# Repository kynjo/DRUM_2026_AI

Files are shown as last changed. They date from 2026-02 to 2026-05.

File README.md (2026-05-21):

# DRUM_2024_AI

All the changes were added using AI

ESP32 DRUM SYNTH MACHINE

DRUM SYNTH LOFI MACHINE.



# Synth engine:

- Wavetable synthesizer based on DZL Arduino library ["The Synth"](https://github.com/dzlonline/the_synth)
- 16 sound polyphony
- MIDI support
- Sound parameters: Table, Length, Envelope, Pitch, Modulation, + Volume, Pan and Filter.
- Filter (LowPassFilter) comes from [Mozzi Library](https://github.com/sensorium/Mozzi)
- Master delay (on 14 button).
- Wavetable's name on screen.
- BPM on main screen.

SEQUENCER:

- 16 step/pattern editor and random generators (pattern, sound parameters and notes)

# Hardware:

- Lolin S2 Mini (ESP32 S2)
- PCM5102A I2s dac
- 24 push buttons (8x3)
- Rotary encoder
- OLED display I2c
- 32 LED WS2812B

# Software:

IDE:
Arduino `1.8.19` 
Arduino `2.3.8`

Boards:
Expressif Systems `2.0.17`

Adafruit TinyUSB `2.4.0`

Board: Lolin S2 Mini

Necessary Libraries:

- Sequencer Timer - [uClock](https://github.com/midilab/uClock)
- RGB Leds - [Adafruit Neopixel](https://github.com/adafruit/Adafruit_NeoPixel)
- OLED - [u8g2](https://github.com/olikraus/u8g2)
- Button input - [Keypad](https://github.com/Chris--A/Keypad)

# Notes:

STL 3D model uploaded.

Cheat sheet style PDF uploaded.

Join solder pads near SCK pin on PCM5102A module.

**Update**: 

- Solder pads on the back of PCM5102A module ([more info](https://github.com/pschatzmann/ESP32-A2DP/wiki/External-DAC#pcm5102-dac))
  
  - H1L: FLT - Low
  
  - H2L: DEMP - Low
  
  - H3L: XSMT - High
  
  - H4L: FMT - Low

Video demo of the prototype:

(https://www.youtube.com/watch?v=rXl1gpWJp-g)

# PCB, PROJECT & FINAL LOOK:

https://oshwlab.com/zircothc/esp32-drum-synth-lofi-machine

https://easyeda.com/editor#project_id=08f629c08b18444ca16accbb2242c0fb





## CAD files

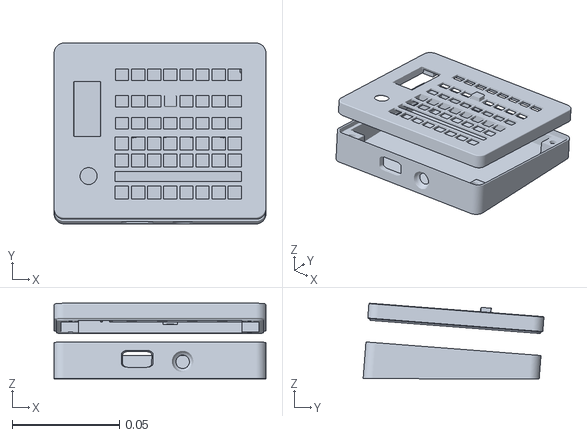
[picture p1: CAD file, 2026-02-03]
STL/all.stl
0.0988 x 0.0843 x 0.0352

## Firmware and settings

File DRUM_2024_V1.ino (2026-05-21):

////////////////////////////
// DRUM 2024              //
////////////////////////////
// ZCARLOS 2024
// Based on DZL's library "the_synth"
// Ported to ESP32 internal DACs but...
// DAC outs sounds very noisy
// Instead of modify the library I cut it into functions to try to port to pcm5102a i2s DAC out, DONE :)
// Extended tables up to 14 and voices up to 16
// Mixer section (L&R) per voice
// Filter per voice and master filter (from Mozzi library)


// includes
#include <Arduino.h>
////////////////////////////// SPIFFS
#include <FS.h>
#include <SPIFFS.h>

////////////////////////////// OLED
#include <U8g2lib.h>
#include <Wire.h>
////////////////////////////// SYNTH
#define SAMPLE_RATE 44100
#include "driver/i2s.h"
#include "synthESP32LowPassFilter_E.h" // filter
#include "tablesESP32_E.h"
//////////////////////////////DELAY
#include "reverbESP32.h"
//////////////////////////////RETRIGGER
#include "retriggerESP32.h"

////////////////////////////// LEDS
#include <Adafruit_NeoPixel.h>
////////////////////////////// TIMER SEQ 
#include <uClock.h>
////////////////////////////// KEYPAD
#include <Keypad.h>
////////////////////////////// MIDI USB
//#include <Adafruit_TinyUSB.h>
//#include <MIDI.h>
//MIDI_CREATE_INSTANCE(HardwareSerial, Serial2, MIDI);
#include <Adafruit_TinyUSB.h>
#include <MIDI.h>

Adafruit_USBD_MIDI usb_midi;
MIDI_CREATE_INSTANCE(Adafruit_USBD_MIDI, usb_midi, MIDI);

////////////////////////////////////////////////////////////////////////////////////////////
////////////////////////////////////////////////////////////////////////////////////////////

////////////////////////////// OLED
U8G2_SSD1306_128X32_UNIVISION_F_HW_I2C u8g2(U8G2_R3, /* reset=*/ U8X8_PIN_NONE, /* clock=*/ 5, /* data=*/ 3);   // pin remapping with ESP8266 HW I2C

const String trot[17] = { "WAV", "ENV", "LEN", "PIT", "MOD", "VOL", "PAN", "FIL", "BPM","MVO","TRP","MFI","OCT","PSN","DLY","RTG"};
const String waveNames[16] = {
  "SIN",  // 0 - Sine
  "TRI",  // 1 - Triangle  
  "SQR",  // 2 - Square
  "SAW",  // 3 - Saw
  "RMP",  // 4 - Ramp
  "NS",   // 5 - Noise
  "PHS",  // 6 - Phasor
  "ADD",   // 14 - Additive (если добавили)
  "SUB",  // 15 - Wave 7
  "WN1",  // 7 - Wave 1
  "WN2",  // 8 - Wave 2
  "WN3",  // 9 - Wave 3
  "WN4",  // 10 - Wave 4
  "WN5",  // 11 - Wave 5
  "WN6",  // 12 - Wave 6
  "WN7"  // 13 - Wave 7  
};
const String tmodeZ[20] = { "Pad", "Sel", "Write", "Mute", "Solo", "Clear","LoadP","LoadS","LoaPS","SaveP","SaveS","SavPS","RndS","RndP","First","Last","Melod","RndNo","Piano","Song"};

// modeZ types

//  0 - play pad sound
//  1 - select sound
//  2 - edit track, write
//  3 - mute
//  4 - solo
//  5 - clear

//  6 - load pattern
//  7 - load pattern
//  8 - load pattern and sound

//  9 - save pattern
// 10 - save sound
// 11 - save sound and pattern
 
// 12 - random sound
// 13 - random pattern
// 14 - first step
// 15 - last step
// 16 - set melodic (read pitch from pattern melodic instead of rotary value)
// 17 - random note
// 18 - piano
// 10 - song (edit song)

#define tPad    0
#define tSel    1
#define tWrite  2
#define tMute   3
#define tSolo   4
#define tClear  5
#define tLoadP  6
#define tLoadS  7
#define tLoaPS  8
#define tSaveP  9
#define tSaveS 10
#define tSavPS 11
#define tRndS  12
#define tRndP  13
#define tFirst 14
#define tLast  15
#define tMelod 16
#define tRndNo 17
#define tPiano 18
#define tSong  19

////////////////////////////// SYNTH
// i2s

#define I2S_BCK_PIN 33
#define I2S_WS_PIN 37
#define I2S_DATA_OUT_PIN 35

#define DMA_BUF_LEN     32          
#define DMA_NUM_BUF     2

static uint16_t out_buf[DMA_BUF_LEN * 2];



// Filters master (L&R) and 16 sounds
LowPassFilter lpfR;
LowPassFilter lpfL;

SimpleReverb masterReverb;
//SimpleRetrigger masterRetrigger; //retrigger

// Массив фильтров для 16 голосов — вместо lpf0..lpf15
LowPassFilter lpf[16];



const int revlevel=200;
const int cutoff=255;
const int reso=511;

int vmeter=0;

static unsigned int PCW[16] = {0, 0, 0, 0,0 ,0 ,0 ,0,0, 0, 0, 0,0 ,0 ,0 ,0};      //-Wave phase accumolators
static unsigned int FTW[16] = {1000, 200, 300, 400, 1000, 200, 300, 400, 1000, 200, 300, 400, 1000, 200, 300, 400};           //-Wave frequency tuning words
static unsigned char AMP[16] = {255, 255, 255, 255, 255, 255, 255, 255, 255, 255, 255, 255, 255, 255, 255, 255};           //-Wave amplitudes [0-255]
static unsigned int PITCH[16] = {500, 500, 500, 500, 500, 500, 500, 500, 500, 500, 500, 500, 500, 500, 500, 500};          //-Voice pitch
static int MOD[16] = {64, 64, 64, 64, 64, 64, 64, 64, 64, 64, 64, 64, 64, 64, 64, 64};                      //-Voice envelope modulation [0-1023 512=no mod. <64 pitch down >64 pitch up]

static int VOL_R[16] = {10, 10, 10, 10, 10, 10, 10, 10, 10, 10, 10, 10, 10, 10, 10, 10}; 
static int VOL_L[16] = {10, 10, 10, 10, 10, 10, 10, 10, 10, 10, 10, 10, 10, 10, 10, 10};   
static int PAN[16] = {10, 10, 10, 10, 10, 10, 10, 10, 10, 10, 10, 10, 10, 10, 10, 10}; 
static int FILTER[16]= {127, 127, 127, 127, 127, 127, 127, 127, 127, 127, 127, 127, 127, 127, 127, 127};                  //-mozzi FILTERS  0-255

static unsigned int wavs[16];                                  //-Wave table selector [address of wave in memory]
static unsigned int envs[16];                                  //-Envelope selector [address of envelope in memory]
static unsigned int EPCW[16] = {0x8000, 0x8000, 0x8000, 0x8000, 0x8000, 0x8000, 0x8000, 0x8000, 0x8000, 0x8000, 0x8000, 0x8000, 0x8000, 0x8000, 0x8000, 0x8000}; //-Envelope phase accumulator
static unsigned int EFTW[16] = {10, 10, 10, 10, 10, 10, 10, 10, 10, 10, 10, 10, 10, 10, 10, 10};               //-Envelope speed tuning word
static unsigned int divider = 16;                             //-Sample rate decimator for envelope

static int mvol=10;
int master_vol=17;
int master_filter=0;
int master_reverb=0;
//int master_retrigger = 0;  //retrigger
int octave=5;



////////////////////////////// LEDS
#define LED_PIN    39
#define LED_COUNT 32
Adafruit_NeoPixel strip(LED_COUNT, LED_PIN, NEO_GRB + NEO_KHZ800);
// Set more friendly led numbers
// 0 to 15 as 16 step, 16 sounds,... and 16 to 23 as selected modes
const byte real_led[32]={ 8, 9,10,11,24,25,26,27,15,14,13,12,31,30,29,28,
                          0, 1, 2, 3,16,17,18,19, 7, 6, 5, 4,23,22,21,20};
int counter_refresh=0;
const byte limit_counter_refresh=7;
boolean start_counter_refresh=false;

////////////////////////////// TIMER SEQ 
int bpm=120;
int stepInterval;
int microStep=0;
byte selected_pattern=0;
byte sstep=0;
byte selected_len=16;
boolean updateBPM=false;
uint16_t mutes=0;
uint16_t solos=0;
uint16_t pattern[16];
byte song[255];
int pattern_song_counter=-1;
byte last_pattern_song=255;
uint8_t  melodic[16][16];
//uint16_t isMelodic=B11111111<<8 | B00000000; // last 8 sounds are set to melodic
uint16_t isMelodic=B00000000<<8 | B00000000; // none set to melodic
byte firstStep=0;
byte lastStep=15;
byte newLastStep=15; 
byte selected_sound=0;
byte oldselected_sound=0;
byte selected_sndSet=0;
int transpose=0;
boolean load_flag=false;

////////////////////////////// ROTARY
void IRAM_ATTR i_ENCODERS();
const byte pinBR1=9;
const byte pinR1A=11;
const byte pinR1B=12;
byte ENC_PORT1=0;
int counter1=0;
int old_counter1=0;
boolean readencoders=false;
byte shiftR1=false;
byte RV;

// 8 sound parameters + bpm + master vol + transpose + master filter + octave + Pattern song selector +  4 Audino parameters
const int max_values[17]={15,4,127,127,127,31, 99,127,400,31, 1,127,10,255,255.255}; 
const int min_values[17]={ 0,0,  0,  0,  0, 0,-99,  0,  0, 0,-1,  0, 0,  0,  1, 0};

int ROTvalue[16][8]={ // init sound values
  { 0,2, 32, 35,29,7,-31,0}, // THIS IS VOICE #0
  { 5,1, 50,127,31,7,-31,0}, // THIS IS VOICE #1
  { 9,2, 25, 41,95,7,  0,0}, // ...
  { 0,0, 60, 64,30,7,  0,0},
  {13,2, 47, 44,82,7,  0,0},
  { 8,2, 42, 29,31,7,  0,0},
  { 0,0, 30, 54,64,7,  0,0},
  { 3,0, 25, 44,64,7,  0,0},
  
  { 0,2, 32, 25,29,7, 66,0},
  { 5,2, 50,107,31,7, 66,0},
  { 9,2, 25, 31,95,7,  0,0},
  { 0,0, 60, 54,30,7,  0,0},
  {13,2, 47, 54,82,7,  0,0},
  { 8,2, 42, 19,31,7,  0,0},
  { 0,0, 40, 44,64,7, 30,0},
  { 3,0, 80, 34,64,7,-30,0}
};

byte selected_rot=0;

////////////////////////////// KEYPAD

const byte ROWS = 8; //four rows
const byte COLS = 3; //three columns
char keys[ROWS][COLS] = {
  {'1','2','3'},
  {'4','5','6'},
  {'7','8','9'},
  {'*','0','#'},
  {'a','s','d'},
  {'z','x','c'},
  {'f','g','h'},
  {'v','b','n'}  
};
// need to confirm if this is the right order in the PCB version
byte rowPins[ROWS] = {14, 13, 10, 8,6,4,2,7}; //connect to the row pinouts of the keypad
byte colPins[COLS] = {40,38,36}; //connect to the column pinouts of the keypad
Keypad kpd = Keypad( makeKeymap(keys), rowPins, colPins, ROWS, COLS );
byte trigger_on[24];
byte nkey;

// Set more friendly key numbers
// 0 to 15 as 16 step, 16 sounds,... and 16 to 23 as selected modes
const byte real_key[24]={ 
 0, 8,16,
 1, 9,17,
 2,10,18,
 3,11,19,
 4,12,20,
 5,13,21,
 6,14,22,
 7,15,23
};

byte pad_touched=0;

////////////////////////////// MISC
byte modeZ=0;
byte last_modeZ=0;
byte last_sound=0;

volatile boolean playing = false;
boolean songing   = false; // switch to make load auto patterns++
boolean recording = false;
//boolean shifting  = false;

boolean clearPATTERN=false;
boolean clearSTEP=false;
boolean refreshPATTERN=true;
boolean refreshSTEP=false;
boolean refreshSTATUS=false;
boolean refreshMODES=true;
boolean refreshOLED=true;
boolean refreshPADTOUCHED=false;
boolean stepzero = false;

// Rate-limit для OLED и LED — не чаще чем раз в N мс
// Это освобождает loop() для обработки MIDI в остальное время
static uint32_t lastOLEDms = 0;
static uint32_t lastLEDms  = 0;
#define OLED_INTERVAL_MS  40   // ~25 fps достаточно для UI
#define LED_INTERVAL_MS   20   // ~50 fps для LED
#define MIDI_CLOCK 0xF8
#define MIDI_START 0xFA
#define MIDI_STOP  0xFC


////////////////////////////////////////////////////////////////////////////////////////////
////////////////////////////////////////////////////////////////////////////////////////////

void setSound(byte f){
  synthESP32_setWave(f,ROTvalue[f][0]);  
  synthESP32_setEnvelope(f,ROTvalue[f][1]);
  synthESP32_setLength(f,ROTvalue[f][2]);
  synthESP32_setPitch(f,ROTvalue[f][3]);
  synthESP32_setMod(f,ROTvalue[f][4]); 
  synthESP32_setVol(f,ROTvalue[f][5]);  
  synthESP32_setPan(f,ROTvalue[f][6]);  
  synthESP32_setFilter(f,ROTvalue[f][7]); 

  //////
}

/*
void handleNoteOn(uint8_t channel, uint8_t pitch, uint8_t velocity) {
  if (velocity == 0) {
    // Velocity 0 также иногда означает Note Off
    return handleNoteOff(channel, pitch, velocity);
  }
  // Воспроизводим ноту на соответствующем канале
  if (pitch < 16) { // Проверяем диапазон (0-15 каналов)
    byte soundChannel = pitch % 16;
    synthESP32_mTrigger(soundChannel, pitch);
  }
}

void handleNoteOff(uint8_t channel, uint8_t pitch, uint8_t velocity) {
  // Тут можно обнулять сэмплы/доп логика
  Serial.println("Note Off");
  // По вашему желанию. Например, отключить звук
}
*/



void setRandomVoice(byte f){
  ROTvalue[f][0]=random(0, 16);
  ROTvalue[f][1]=random(0, 5);
  ROTvalue[f][2]=random(1, 60);
  ROTvalue[f][3]=random(0, 127);
  ROTvalue[f][4]=random(10,100);
  ROTvalue[f][5]=random(10,15);
  ROTvalue[f][6]=random(-99,99);
  ROTvalue[f][7]=random(0,60);
}
void setRandomPattern(byte f){
  byte veces=random(0,2);
  for (byte b = 0; b < 16; b++) {
    byte mybit=random(0,2);
    if (veces) {
      if (mybit) mybit=random(0,2); // Si es 1 hago otro random para que haya menos unos
    }
    bitWrite(pattern[f],b,mybit);
  } 
  setRandomPitch(f);
}

void setRandomPitch(byte f){
  // Tomo como referencia para el rango el valor del pot pitch actual
  uint8_t actual=ROTvalue[selected_sound][3];
  uint8_t limite;
  uint8_t prelimite=24;
  if (shiftR1) prelimite = 24;
  for (byte b = 0; b < 16; b++) {
     limite=actual+random(0,prelimite);
     melodic[f][b]=random(actual-(prelimite>>1),limite);
  }  
}

void setRandomNotes(byte f){
  setRandomPitch(f);
}
////////////////////////////////////////////////////////////////////////////////////////////
////////////////////////////////////////////////////////////////////////////////////////////
void onSync24Callback(uint32_t tick){
  if (!playing) return;  // ISR не должен продолжать после Stop
  if (!(tick % (6))) tic(tick);
  if ((tick % (6))==4) clearPATTERN=true;
}

void tic(uint32_t tick){
  
//  if (playing){
    //if (microStep==0){
      clearSTEP=true;
      for (int f = 0; f < 16; f++) { 
        if (!bitRead(mutes, f)) {
          if (solos == 0 || (solos > 0 && bitRead(solos, f))) {
            if (bitRead(pattern[f], sstep)) { // note on
              if (bitRead(isMelodic,f)){
                //synthESP32_setPitch(f,melodic[f][sstep]);

                  synthESP32_mTrigger(f,melodic[f][sstep]);                  

              } else {
                // reestablecer el pitch
                synthESP32_setPitch(f,ROTvalue[f][3]);                
                synthESP32_trigger(f);
              }
            } 
          }
        }
      }
  
      sstep++;
      // Comprobar step final
      if (sstep==(lastStep+1) || sstep==(newLastStep+1) || (stepzero) || sstep==16) {
        lastStep=newLastStep;
        stepzero=false;
        sstep=firstStep;
        //Serial.println("Toc");
        if (songing){
          load_flag=true; // inside loop I will load next pattern
        }
      }
      refreshSTEP=true;
      refreshPATTERN=true; 
//    }


    

}
////////////////////////////////////////////////////////////////////////////////////////////
////////////////////////////////////////////////////////////////////////////////////////////

void load_pattern(byte pat){
  
  // Leer pattren
  String nombreArchivoP = "/PAT" + String(pat);
  File archivoP = SPIFFS.open(nombreArchivoP, FILE_READ);   
  if (!archivoP) {
    Serial.println("Error al abrir el archivo para leer");
    return;
  }
  int fila = 0;
  while (archivoP.available()) {
    pattern[fila] = (archivoP.readStringUntil('\n')).toInt();
    //Serial.println(pattern[fila]);
    fila++;
  }
  archivoP.close();
  //Serial.println("-");


  // Leer melodic
  String nombreArchivoM = "/MED" + String(pat);
  File archivoM = SPIFFS.open(nombreArchivoM, FILE_READ);
  if (!archivoM) {
    Serial.println("Error al abrir el archivo para leer");
    return;
  }
  fila = 0;
  int columna = 0;  
  while (archivoM.available()) {
    melodic[fila][columna] = (archivoM.readStringUntil('\n')).toInt();
    columna++;
    if (columna == 16) {
      fila++;
      columna = 0;
    }
  }
  archivoM.close(); 

  
}

void load_sound(byte pat){
  
  // Leer sound
  String nombreArchivoS = "/SND" + String(pat);
  File archivoS = SPIFFS.open(nombreArchivoS, FILE_READ);
  if (!archivoS) {
    Serial.println("Error al abrir el archivo para leer");
    return;
  }
  int fila = 0;
  int columna = 0;  
  while (archivoS.available()) {
    ROTvalue[fila][columna] = (archivoS.readStringUntil('\n')).toInt();
    columna++;
    if (columna == 8) {
      // Set voices
      setSound(fila);
      fila++;
      columna = 0;
    }
  }
  archivoS.close(); 

}

void save_pattern(byte pat){
  
  // Guardar pattern
  String nombreArchivoP = "/PAT" + String(pat);
  File archivoP = SPIFFS.open(nombreArchivoP, FILE_WRITE);   
  if (!archivoP) {
    Serial.println("Error al abrir el archivo para escribir");
    return;
  }
  for (int i = 0; i < 16; i++) {
    archivoP.println(pattern[i]);
    //Serial.println(pattern[i]);
  }
  archivoP.close();
  //Serial.println("-");  

  // Guardar melodic
  String nombreArchivoM = "/MED" + String(pat);
  File archivoM = SPIFFS.open(nombreArchivoM, FILE_WRITE); 
  if (!archivoM) {
    Serial.println("Error al abrir el archivo para escribir");
    return;
  }
  for (int i = 0; i < 16; i++) {
    for (int j = 0; j < 16; j++) {
      archivoM.println(melodic[i][j]);
    }
  }
  archivoM.close();

  
}
void save_sound(byte pat){
  
  // Guardar sound
  String nombreArchivoS = "/SND" + String(pat);
  File archivoS = SPIFFS.open(nombreArchivoS, FILE_WRITE); 
  if (!archivoS) {
    Serial.println("Error al abrir el archivo para escribir");
    return;
  }
  for (int i = 0; i < 16; i++) {
    for (int j = 0; j < 8; j++) {
      archivoS.println(ROTvalue[i][j]);
    }
  }
  archivoS.close();

}


void startupAnimation() {
  // Бегущая точка по всем LED
  for (int i = 0; i < 32; i++) {
    strip.setPixelColor(real_led[i], strip.Color(0, 100, 200)); // Синий
    strip.show();
    delay(20); // Быстрая анимация
    strip.setPixelColor(real_led[i], strip.Color(0, 0, 0));
  }
  
  // Мигание всех LED 3 раза
  for (int j = 0; j < 3; j++) {
    // Включить все
    for (int i = 0; i < 32; i++) {
      strip.setPixelColor(real_led[i], strip.Color(80, 80, 80)); // Белый
    }
    strip.show();
    delay(80);
    
    // Выключить все
    for (int i = 0; i < 32; i++) {
      strip.setPixelColor(real_led[i], strip.Color(0, 0, 0));
    }
    strip.show();
    if (j < 2) delay(80); // Не ждать после последнего мигания
  }
  
  // Зажечь текущий выбранный звук

}

////////////////////////////////////////////////////////////////////////////////////////////
////////////////////////////////////////////////////////////////////////////////////////////

//////////////////////////////  S E T U P  //////////////////////////////
void setup() {
  btStop();
  // Serial
  Serial.begin(115200);
  // MISI USB
 /*MIDI.begin(MIDI_CHANNEL_OMNI);
  MIDI.setHandleNoteOn(handleNoteOn);  
  MIDI.setHandleControlChange(handleCC);
  // check device mounted
  if ( !TinyUSBDevice.mounted() ){
    Serial.println("Error USB");
 }*/
  // USB MIDI init (TinyUSB)
  usb_midi.begin();
  // Ждём монтирования USB-устройства хостом (ПК)
  // Timeout 3 секунды — если нет ПК, продолжаем без MIDI
  uint32_t t0 = millis();
  while (!TinyUSBDevice.mounted() && millis() - t0 < 3000) delay(10);

  MIDI.begin(MIDI_CHANNEL_OMNI);
  MIDI.setHandleNoteOn(handleNoteOn);
  MIDI.setHandleNoteOff(handleNoteOff);
  MIDI.setHandleControlChange(handleCC);
  MIDI.setHandleClock(handleClock);
  MIDI.setHandleStart(handleStart);
  MIDI.setHandleStop(handleStop);
  MIDI.setHandleContinue(handleContinue);
  MIDI.setHandleSongPosition(handleSongPosition);
  Serial.println("USB MIDI Initialized!");
  // Synth
  synthESP32_begin();
  // Set 16 voices
  for (byte f=0;f<16;f++){
    setSound(f);
  }
  // Set master vol
  synthESP32_setMVol(master_vol);
  // Set master filter
  synthESP32_setMFilter(master_filter);  
    // Set master reverb (ДОБАВЬТЕ)
  synthESP32_setMReverb(master_reverb);
  
  // SPIFFS
  if (!SPIFFS.begin(true)) {
    Serial.println("Error al montar el sistema de archivos SPIFFS");
    return;
  } 
  
  // Leds
  strip.begin();
  strip.clear();           
  strip.show();            
  strip.setBrightness(50);
  startupAnimation();
    delay(100); // Пауза после анимации
  // Seq


   // fill melodic with 60
  for  (byte a=0;a<16;a++){
    for  (byte b=0;b<16;b++){
     melodic[a][b]=60;
    }    
  }
  // set 8-15 as melodic;
  isMelodic=B11111111<<8 | B00000000;
  // Setup our clock system
  uClock.init();
  //uClock.setOnStep(onStepCallback);
  uClock.setOnSync24(onSync24Callback);
  uClock.setTempo(bpm);

//    // demo pattern
//    pattern[0]=B00010001<<8 | B10010001;
//    pattern[2]=B11000101<<8 | B10101011;
//    pattern[6]=B10110101<<8 | B10001111;
//    pattern[3]=B00000110<<8 | B00000000;
//    pattern[7]=B00000000<<8 | B01001000;
//    // start playing demo pattern
//    uClock.start();
//    sstep=firstStep;
//    refreshSTEP=true; 
//    playing=true;
  // Oled
  u8g2.begin();
  // Rotary
  pinMode(pinR1A,INPUT_PULLUP);
  pinMode(pinR1B,INPUT_PULLUP);
  pinMode(pinBR1,INPUT_PULLUP);
  attachInterrupt(pinR1A, i_ENCODERS, CHANGE);  
  attachInterrupt(pinR1B, i_ENCODERS, CHANGE);  
}

//////////////////////////////  L O O P  //////////////////////////////

void loop() {

  // flag to do things outside sequencer timer isr
  if (load_flag){
    load_flag=false;

    pattern_song_counter++;
    if (pattern_song_counter==255) pattern_song_counter=0;
    if (pattern_song_counter>last_pattern_song) pattern_song_counter=0; 
        
    load_pattern(song[pattern_song_counter]);
    selected_pattern=song[pattern_song_counter];
    load_sound(song[pattern_song_counter]);
    selected_sndSet=song[pattern_song_counter];
           
    refreshOLED=true;
  }

  // Вычитываем весь MIDI буфер — приоритет
  while (MIDI.read());

  shiftR1=!digitalRead(pinBR1);
  READ_ENCODERS();
  READ_KEYPAD();
  DO_KEYPAD();

  // LED: не чаще LED_INTERVAL_MS — strip.show() блокирует ~1-2ms
  uint32_t now = millis();
  if (now - lastLEDms >= LED_INTERVAL_MS) {
    lastLEDms = now;
    REFRESH_LEDS();
  }

  // OLED: не чаще OLED_INTERVAL_MS — sendBuffer() блокирует ~3-5ms
  if (now - lastOLEDms >= OLED_INTERVAL_MS) {
    lastOLEDms = now;
    REFRESH_OLED_OPTIMIZED();
  }

  REFRESH_VUMETER();


}

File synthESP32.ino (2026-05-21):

void  synthESP32_begin(){

 // Инициализация реверба (аналогично фильтрам)
  masterReverb.setLevel(0);
  
  lpfL.setResonance(reso);
  lpfR.setResonance(reso);
 
  lpfL.setCutoffFreq(cutoff);
  lpfR.setCutoffFreq(cutoff); 
  
  for (int i = 0; i < 16; i++) {
    lpf[i].setResonance(reso);
    lpf[i].setCutoffFreq(cutoff);
  }

      
  i2s_config_t i2s_config = {
    .mode = (i2s_mode_t)(I2S_MODE_MASTER | I2S_MODE_TX ),
    .sample_rate = SAMPLE_RATE,
    .bits_per_sample = I2S_BITS_PER_SAMPLE_16BIT,
    .channel_format = I2S_CHANNEL_FMT_RIGHT_LEFT,
    .communication_format = (i2s_comm_format_t)(I2S_COMM_FORMAT_I2S | I2S_COMM_FORMAT_I2S_MSB),
    //.communication_format = (i2s_comm_format_t)(I2S_COMM_FORMAT_I2S | I2S_COMM_FORMAT_I2S_LSB),
    .intr_alloc_flags = ESP_INTR_FLAG_LEVEL2,
    .dma_buf_count = DMA_NUM_BUF,
    .dma_buf_len = DMA_BUF_LEN,
    .use_apll = true,
  };

  i2s_pin_config_t i2s_pin_config = {
    .bck_io_num = I2S_BCK_PIN,
    .ws_io_num =  I2S_WS_PIN,
    .data_out_num = I2S_DATA_OUT_PIN
  };


  i2s_driver_install(I2S_NUM_0, &i2s_config, 0, NULL);

  i2s_set_pin(I2S_NUM_0, &i2s_pin_config);
  //i2s_zero_dma_buffer(I2S_NUM_0);


    // Highest possible priority for realtime audio task
    xTaskCreate(audio_task, "audio", 8000, NULL, configMAX_PRIORITIES - 1, NULL); 
}
static void write_buffer() {
	
	size_t bytes_written;

  for (int i=0; i < DMA_BUF_LEN; i++) {
	
	
  //-------------------------------
  // Time division
  //-------------------------------
  divider++;
  if (divider>=16) divider=0;
  
  //-------------------------------
  // Volume envelope generator
  //-------------------------------

   if (!(((unsigned char*)&EPCW[divider])[1]&0x80)) {
   AMP[divider] = wenvs[envs[divider]][ (((unsigned char*)&(EPCW[divider]+=EFTW[divider]))[1])];

	
  } else {
    AMP[divider] = 0;
  }
  
	
  //-------------------------------
  //  Synthesizer/audio mixer
  //-------------------------------

	// Generate sounds
	
  // static: не выделяется на стеке 32 раза за вызов write_buffer()
  static int32_t sound_A[16];
 
  sound_A[0]=(((signed char)(wtables[wavs[0] ][((unsigned char *)&(PCW[0]  += FTW[0] ))[1]]) * AMP[0]   ) >> 8);
	sound_A[1]=(((signed char)(wtables[wavs[1] ][((unsigned char *)&(PCW[1]  += FTW[1] ))[1]]) * AMP[1]   ) >> 8);
	sound_A[2]=(((signed char)(wtables[wavs[2] ][((unsigned char *)&(PCW[2]  += FTW[2] ))[1]]) * AMP[2]   ) >> 8);
	sound_A[3]=(((signed char)(wtables[wavs[3] ][((unsigned char *)&(PCW[3]  += FTW[3] ))[1]]) * AMP[3]   ) >> 8);
	sound_A[4]=(((signed char)(wtables[wavs[4] ][((unsigned char *)&(PCW[4]  += FTW[4] ))[1]]) * AMP[4]   ) >> 8);
	sound_A[5]=(((signed char)(wtables[wavs[5] ][((unsigned char *)&(PCW[5]  += FTW[5] ))[1]]) * AMP[5]   ) >> 8);
	sound_A[6]=(((signed char)(wtables[wavs[6] ][((unsigned char *)&(PCW[6]  += FTW[6] ))[1]]) * AMP[6]   ) >> 8);	
	sound_A[7]=(((signed char)(wtables[wavs[7] ][((unsigned char *)&(PCW[7]  += FTW[7] ))[1]]) * AMP[7]   ) >> 8);	
	sound_A[8]=(((signed char)(wtables[wavs[8] ][((unsigned char *)&(PCW[8]  += FTW[8] ))[1]]) * AMP[8]   ) >> 8);	
	sound_A[9]=(((signed char)(wtables[wavs[9] ][((unsigned char *)&(PCW[9]  += FTW[9] ))[1]]) * AMP[9]   ) >> 8);	
	sound_A[10]=(((signed char)(wtables[wavs[10] ][((unsigned char *)&(PCW[10]  += FTW[10] ))[1]]) * AMP[10]   ) >> 8);
	sound_A[11]=(((signed char)(wtables[wavs[11] ][((unsigned char *)&(PCW[11]  += FTW[11] ))[1]]) * AMP[11]   ) >> 8);
	sound_A[12]=(((signed char)(wtables[wavs[12] ][((unsigned char *)&(PCW[12]  += FTW[12] ))[1]]) * AMP[12]   ) >> 8);
	sound_A[13]=(((signed char)(wtables[wavs[13] ][((unsigned char *)&(PCW[13]  += FTW[13] ))[1]]) * AMP[13]   ) >> 8);
	sound_A[14]=(((signed char)(wtables[wavs[14] ][((unsigned char *)&(PCW[14]  += FTW[14] ))[1]]) * AMP[14]   ) >> 8);
	sound_A[15]=(((signed char)(wtables[wavs[15] ][((unsigned char *)&(PCW[15]  += FTW[15] ))[1]]) * AMP[15]   ) >> 8);


  //taskYIELD(); 
  
  // tracks filter
  for (int i = 0; i < 16; i++) {
    sound_A[i] = lpf[i].next(sound_A[i]);
  }




  taskYIELD(); 
  
	// L & R outputs
	
	int32_t loutput= 127 +
	((
	((sound_A[0] * VOL_L[0]   ) >> 3 )+
	((sound_A[1] * VOL_L[1]   ) >> 3 )+
	((sound_A[2] * VOL_L[2]   ) >> 3 )+
	((sound_A[3] * VOL_L[3]   ) >> 3 )+
	((sound_A[4] * VOL_L[4]   ) >> 3 )+
	((sound_A[5] * VOL_L[5]   ) >> 3 )+
	((sound_A[6] * VOL_L[6]   ) >> 3 )+
	((sound_A[7] * VOL_L[7]   ) >> 3 )+
	((sound_A[8] * VOL_L[8]   ) >> 3 )+
	((sound_A[9] * VOL_L[9]   ) >> 3 )+
	((sound_A[10]* VOL_L[10]  ) >> 3 )+
	((sound_A[11]* VOL_L[11]  ) >> 3 )+
	((sound_A[12]* VOL_L[12]  ) >> 3 )+
	((sound_A[13]* VOL_L[13]  ) >> 3 )+
	((sound_A[14]* VOL_L[14]  ) >> 3 )+
	((sound_A[15]* VOL_L[15]  ) >> 3 ) 
    ) >> 3);




  //loutput += delay1.next(loutput)>>1;
	
	int32_t routput= 127 +
	((
	((sound_A[0] * VOL_R[0]   ) >> 3 )+
	((sound_A[1] * VOL_R[1]   ) >> 3 )+
	((sound_A[2] * VOL_R[2]   ) >> 3 )+
	((sound_A[3] * VOL_R[3]   ) >> 3 )+
	((sound_A[4] * VOL_R[4]   ) >> 3 )+
	((sound_A[5] * VOL_R[5]   ) >> 3 )+
	((sound_A[6] * VOL_R[6]   ) >> 3 )+
	((sound_A[7] * VOL_R[7]   ) >> 3 )+
	((sound_A[8] * VOL_R[8]   ) >> 3 )+
	((sound_A[9] * VOL_R[9]   ) >> 3 )+
	((sound_A[10]* VOL_R[10]  ) >> 3 )+
	((sound_A[11]* VOL_R[11]  ) >> 3 )+
	((sound_A[12]* VOL_R[12]  ) >> 3 )+
	((sound_A[13]* VOL_R[13]  ) >> 3 )+
	((sound_A[14]* VOL_R[14]  ) >> 3 )+
	((sound_A[15]* VOL_R[15]  ) >> 3 ) 
    ) >> 3); 
  

	uint8_t lrefilter=lpfL.next(loutput)<<0;
	uint8_t rrefilter=lpfR.next(routput)<<0;
	

	int16_t lsample_out=(lrefilter*mvol)>>5;
	int16_t rsample_out=(rrefilter*mvol)>>5;

        // ============ APPLY REVERB (after master filter) ============
      //if (master_reverb > 0) {
  masterReverb.process(lsample_out, rsample_out);
      //}
  // ============================================================	

/////////////////////RETRIGGER////////////
// Apply retrigger to each voice
/*
  if (master_retrigger > 0) {
    for (int v = 0; v < 16; v++) {
      masterRetrigger.processVoice(v, sound_A[v]);
    }
  }
  */

    // Простая мягкая сатурация (улучшает звук, убирает резкость)
  lsample_out = lsample_out - (lsample_out*lsample_out*lsample_out)/(3*32768*32768);
  rsample_out = rsample_out - (rsample_out*rsample_out*rsample_out)/(3*32768*32768);
  
  if (lsample_out > 240) lsample_out = 240 + (lsample_out-240)/3;
  if (rsample_out > 240) rsample_out = 240 + (rsample_out-240)/3;
  if (lsample_out < -240) lsample_out = -240 + (lsample_out+240)/3;
  if (rsample_out < -240) rsample_out = -240 + (rsample_out+240)/3; 

  out_buf[i*2]   = (uint16_t)lsample_out<<8;  
  out_buf[i*2+1] = (uint16_t)rsample_out<<8;


    //************************************************
    //  Modulation engine
    //************************************************

    FTW[divider] = PITCH[divider] + (int)   (((PITCH[divider]>>6)*(EPCW[divider]>>6))>>7)*MOD[divider];
  
	} // fin bucle del buffer de audio

  // escribir buffer audio
  
	i2s_write(I2S_NUM_0, out_buf, sizeof(out_buf), &bytes_written, portMAX_DELAY);
	
}
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

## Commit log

2026-02-03 Add files via upload
    added new case. with back cover, buttons
    [all.stl, knob.stl]
2026-04-19 Create midi_usb.ino with complete MIDI USB support for ESP32 Lolin S2 Mini
2026-05-21 Add initial readme for STL files
